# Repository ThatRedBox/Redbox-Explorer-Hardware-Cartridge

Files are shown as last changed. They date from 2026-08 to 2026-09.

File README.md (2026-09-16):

Redbox banner

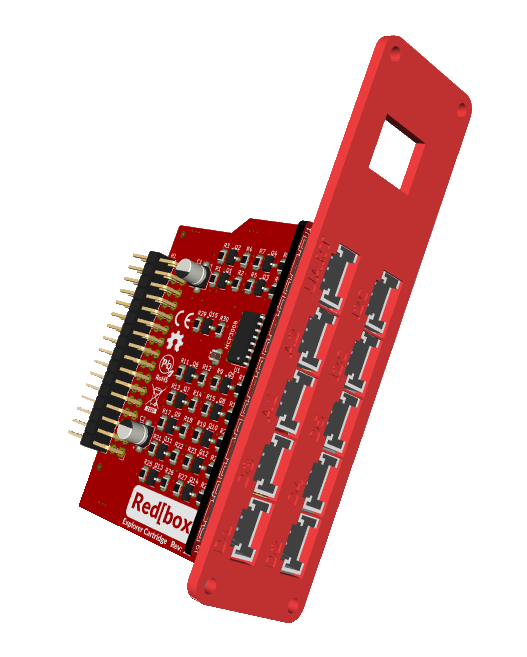
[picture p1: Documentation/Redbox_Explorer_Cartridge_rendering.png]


The **Redbox Explorer Hardware Cartridge** is designed for easily connecting sensors, actuators, and other peripherals to your system. It features the widely used `HY2.0-4P` connector (commonly referred to as the _Grove_ connector), compatible with modules and breakouts from popular ecosystems like [Grove](https://www.seeedstudio.com/catalogsearch/result/?q=grove), [Crowtail](https://www.elecrow.com/catalog/category/view/s/crowtail/id/13/), and [STEMMA](https://www.adafruit.com/category/1005).

#### Ports:
- **5x Digital in/out** (with PWM on D1)
- **2x Analog input** (0-5V)
- **1x UART**
- **2x I2C**

<br/>

 <br/>


<br clear="right"/>

## Usage

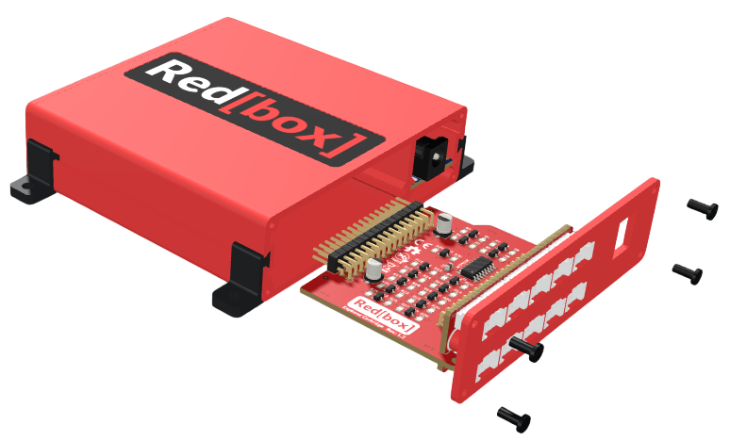
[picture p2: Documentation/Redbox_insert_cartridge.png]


The _Explorer Hardware Cartridge_ slides into the expansion slot in the back of the controller. The faceplate model for 3D printing can be found [here](Documentation/Redbox_Explorer_Cartridge_faceplate.stl). 

Connect modules from a wide range of ecosystems using the `HY2.0-4P` connector to their respective port type (analog/digital/...).

<br clear="right"/>

### Layout

| Port | Type | Raspberry Pi GPIO Pin | Info |
|---|---|---|---|
| **D1** | Digital I/O  | GPIO12 <br/>GPIO20 | Hardware PWM capable* |
| **D2** | Digital I/O  | GPIO21 <br/>GPIO16 | |
| **D3** | Digital I/O  | GPIO13 <br/>GPIO24 | |
| **D4** | Digital I/O  | GPIO25 <br/>GPIO22 | |
| **D5** | Digital I/O  | GPIO23 <br/>GPIO27 | |
| **A1** | Analog input <br/> 0...5V | *ADC* CH0 <br/>*ADC* CH1  | via MCP3008 on SPI |
| **A2** | Analog input <br/> 0...5V | *ADC* CH2 <br/>*ADC* CH3  | via MCP3008 on SPI |
| **I2C**  | I2C bus | I2C SDA <br/>I2C SDL | |
| **UART** | Serial bus | UART RX <br/>UART TX | |

_*Hardware PWM on Raspberry Pi 3B+/4B/5B/Zero 2W_

>[!WARNING]
>The digital I/O lines on this Hardware Cartridge use a passive N-MOSFET level-shifting circuit designed for compatibility with standard open-drain and push-pull I/O configurations.

## License & Collaboration
**Copyright© 2024-2026 Sanne 'SpuQ' Santens**. This project is released under the **CERN OHL-W** license. Rules & guidelines apply to the usage of the Redbox brand.

### Collaboration

If you'd like to contribute to this project, please follow these guidelines:
1. Fork the repository and create your branch from `main`.
2. Make your changes and ensure they adhere to the project's design style and conventions.
3. Test your changes thoroughly.
4. Ensure your commits are descriptive and well-documented.
5. Open a pull request, describing the changes you've made and the problem or feature they address.

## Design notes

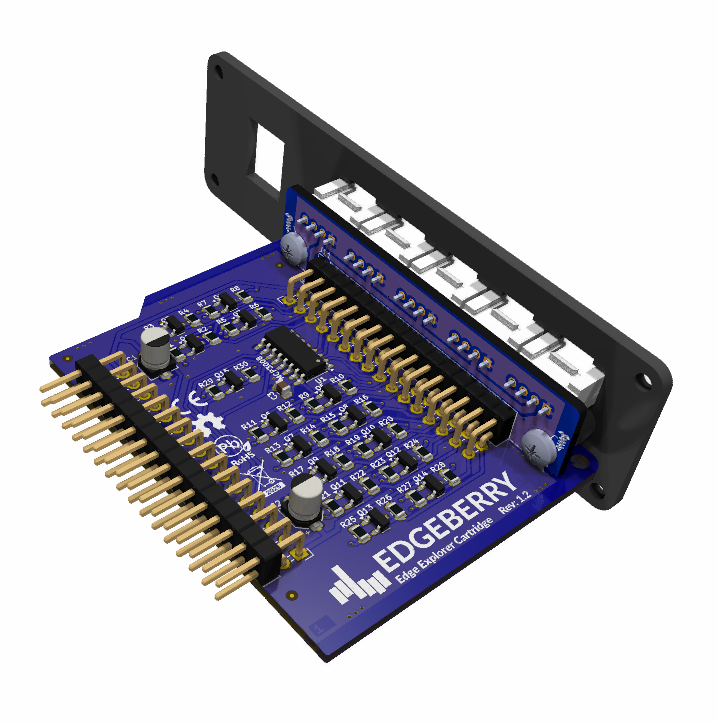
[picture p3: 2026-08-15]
Documentation/Redbox_Explorer_Cartridge_screws_2.png

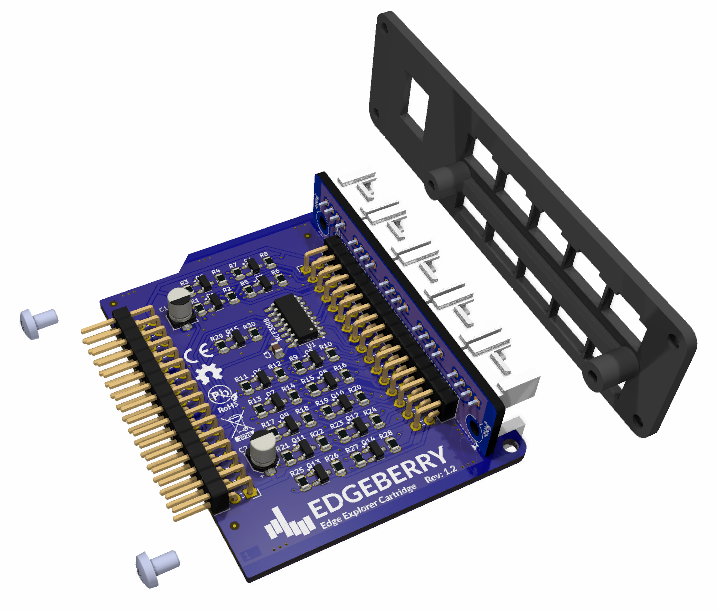
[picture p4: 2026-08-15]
Documentation/Redbox_Explorer_Cartridge_screws_1.png

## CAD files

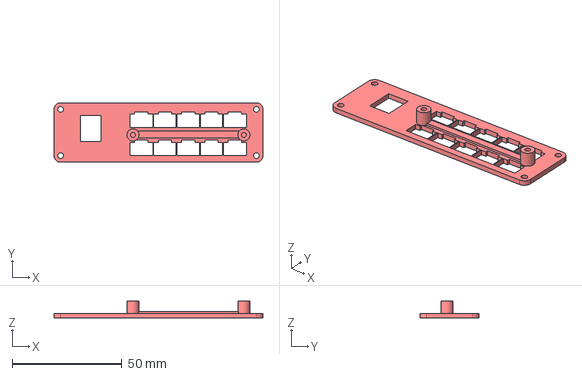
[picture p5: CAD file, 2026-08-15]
Documentation/Redbox_Explorer_Cartridge_faceplate.step
95.0 x 27.0 x 7.70 mm

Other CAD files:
Enclosure/Redbox_Explorer_Cartridge_faceplate.FCStd
Documentation/Redbox_Explorer_Cartridge_faceplate.stl

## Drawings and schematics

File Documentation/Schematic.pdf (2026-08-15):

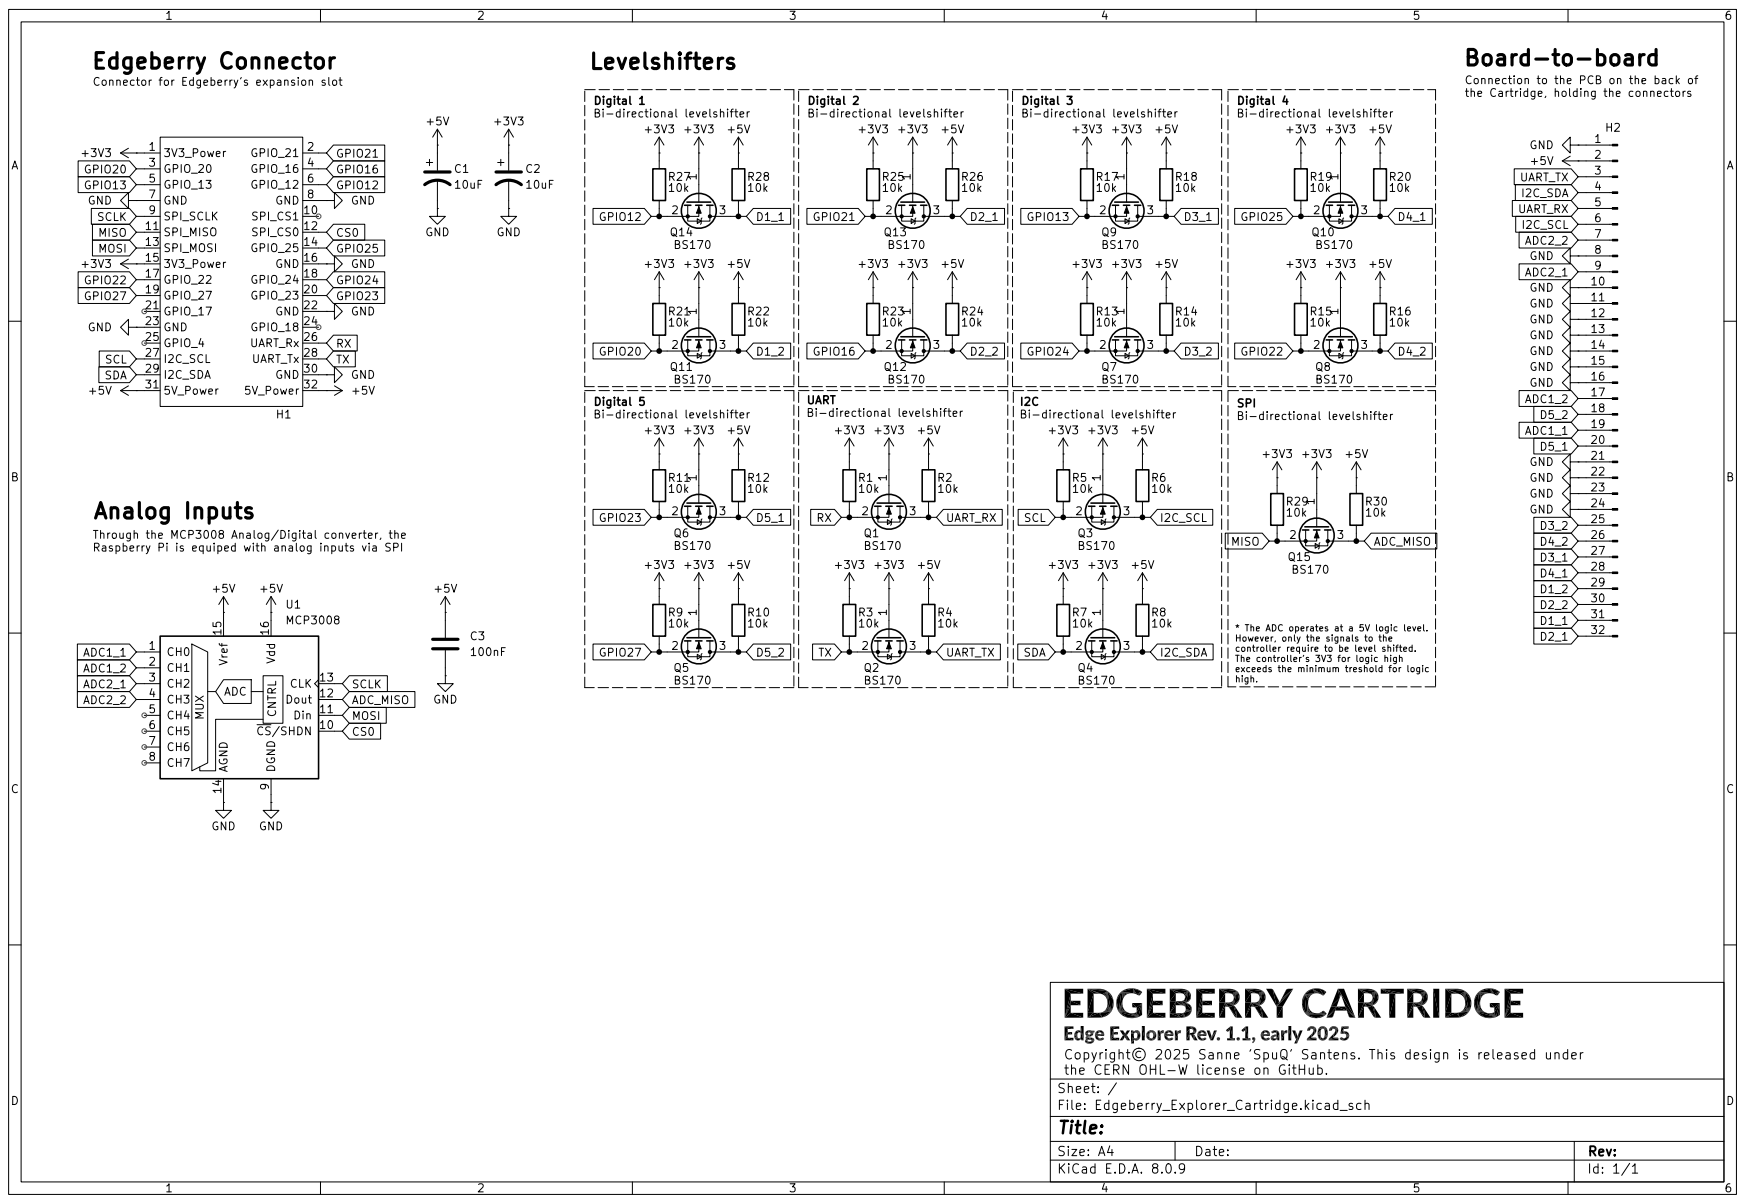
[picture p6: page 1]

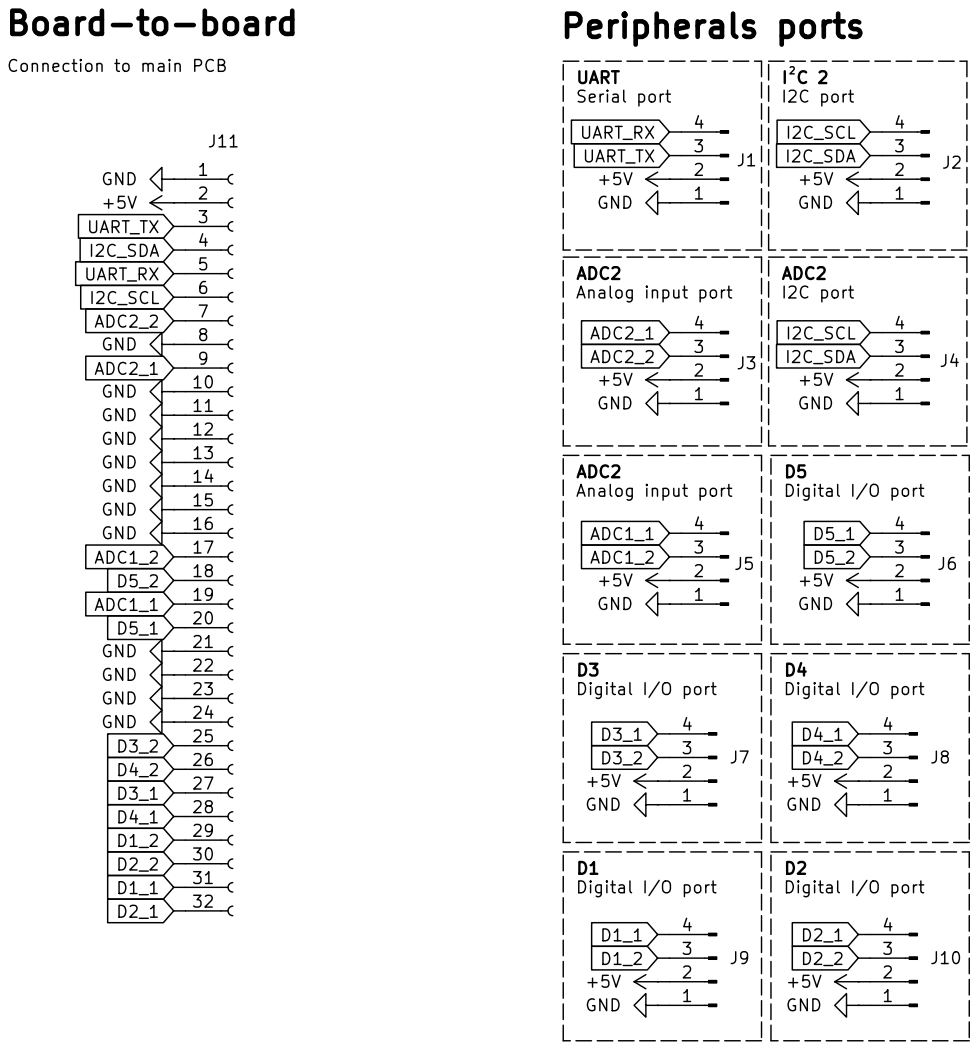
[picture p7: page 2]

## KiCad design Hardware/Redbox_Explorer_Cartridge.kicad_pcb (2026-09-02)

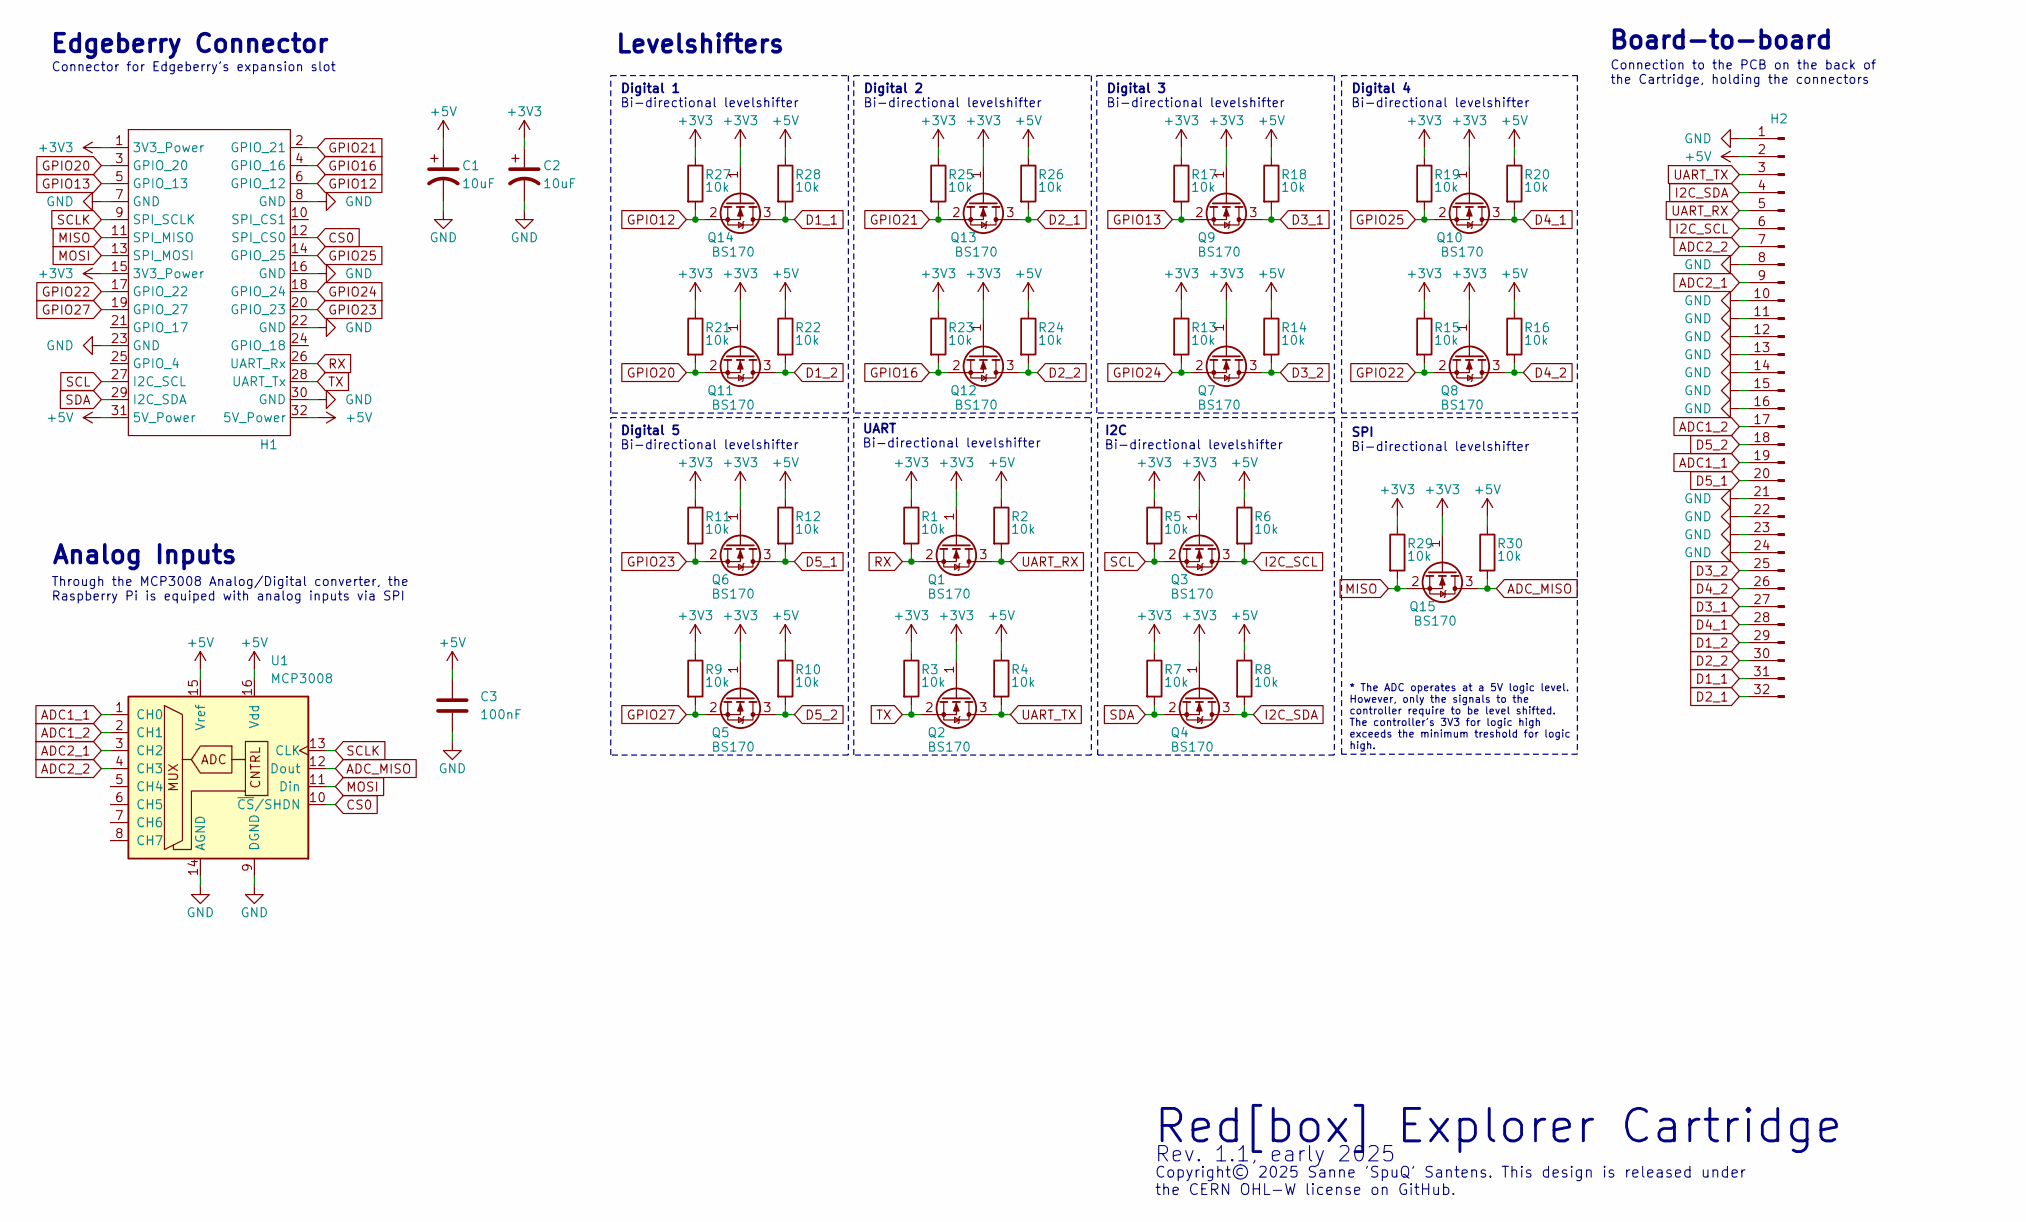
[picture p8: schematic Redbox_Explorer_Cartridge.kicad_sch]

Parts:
C1, C2: 10uF; CP_Elec_4x5.4
C3: 100nF; C_0805_2012Metric
H1: PinHeader_2x16_P2.54mm_Horizontal
H2: Conn_01x32_Pin; PinHeader_2x16_P2.54mm_Horizontal
Q1, Q2, Q3, Q4, Q5, Q6, Q7, Q8, Q9, Q10, Q11, Q12, Q13, Q14, Q15: BS170; SOT-23
R1, R2, R3, R4, R5, R6, R7, R8, R9, R10, R11, R12, R13, R14, R15, R16, R17, R18, R19, R20, R21, R22, R23, R24, R25, R26, R27, R28, R29, R30: 10k; R_0805_2012Metric
U1: MCP3008; SOIC-16_3.9x9.9mm_P1.27mm

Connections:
+3V3: C2.1, H1.1 (3V3_Power), H1.15 (3V3_Power), Q1.1 (G), Q2.1 (G), Q3.1 (G), Q4.1 (G), Q5.1 (G), Q6.1 (G), Q7.1 (G), Q8.1 (G), Q9.1 (G), Q10.1 (G), Q11.1 (G), Q12.1 (G), Q13.1 (G), Q14.1 (G), Q15.1 (G), R1.1, R3.1, R5.1, R7.1, R9.1, R11.1, R13.1, R15.1, R17.1, R19.1, R21.1, R23.1, R25.1, R27.1, R29.1
+5V: C1.1, C3.1, H1.31 (5V_Power), H1.32 (5V_Power), H2.2, R2.1, R4.1, R6.1, R8.1, R10.1, R12.1, R14.1, R16.1, R18.1, R20.1, R22.1, R24.1, R26.1, R28.1, R30.1, U1.15 (Vref), U1.16 (Vdd)
ADC1_1: H2.19, U1.1 (CH0)
ADC1_2: H2.17, U1.2 (CH1)
ADC2_1: H2.9, U1.3 (CH2)
ADC2_2: H2.7, U1.4 (CH3)
ADC_MISO: Q15.3 (D), R30.2, U1.12 (Dout)
CS0: H1.12 (SPI_CS0), U1.10 (~CS/SHDN)
D1_1: H2.31, Q14.3 (D), R28.2
D1_2: H2.29, Q11.3 (D), R22.2
D2_1: H2.32, Q13.3 (D), R26.2
D2_2: H2.30, Q12.3 (D), R24.2
D3_1: H2.27, Q9.3 (D), R18.2
D3_2: H2.25, Q7.3 (D), R14.2
D4_1: H2.28, Q10.3 (D), R20.2
D4_2: H2.26, Q8.3 (D), R16.2
D5_1: H2.20, Q6.3 (D), R12.2
D5_2: H2.18, Q5.3 (D), R10.2
GND: C1.2, C2.2, C3.2, H1.7 (GND), H1.8 (GND), H1.16 (GND), H1.22 (GND), H1.23 (GND), H1.30 (GND), H2.1, H2.8, H2.10, H2.11, H2.12, H2.13, H2.14, H2.15, H2.16, H2.21, H2.22, H2.23, H2.24, U1.9 (DGND), U1.14 (AGND)
GPIO12: H1.6 (GPIO_12), Q14.2 (S), R27.2
GPIO13: H1.5 (GPIO_13), Q9.2 (S), R17.2
GPIO16: H1.4 (GPIO_16), Q12.2 (S), R23.2
GPIO20: H1.3 (GPIO_20), Q11.2 (S), R21.2
GPIO21: H1.2 (GPIO_21), Q13.2 (S), R25.2
GPIO22: H1.17 (GPIO_22), Q8.2 (S), R15.2
GPIO23: H1.20 (GPIO_23), Q6.2 (S), R11.2
GPIO24: H1.18 (GPIO_24), Q7.2 (S), R13.2
GPIO25: H1.14 (GPIO_25), Q10.2 (S), R19.2
GPIO27: H1.19 (GPIO_27), Q5.2 (S), R9.2
I2C_SCL: H2.6, Q3.3 (D), R6.2
I2C_SDA: H2.4, Q4.3 (D), R8.2
MISO: H1.11 (SPI_MISO), Q15.2 (S), R29.2
MOSI: H1.13 (SPI_MOSI), U1.11 (Din)
RX: H1.26 (UART_Rx), Q1.2 (S), R1.2
SCL: H1.27 (I2C_SCL), Q3.2 (S), R5.2
SCLK: H1.9 (SPI_SCLK), U1.13 (CLK)
SDA: H1.29 (I2C_SDA), Q4.2 (S), R7.2
TX: H1.28 (UART_Tx), Q2.2 (S), R3.2
UART_RX: H2.5, Q1.3 (D), R2.2
UART_TX: H2.3, Q2.3 (D), R4.2

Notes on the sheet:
Bi-directional levelshifter
Edgeberry Connector
SPI
Digital 4
Board-to-board
Digital 3
Digital 2
Connection to the PCB on the back of the Cartridge, holding the connectors
I2C
* The ADC operates at a 5V logic level. However, only the signals to the controller require to be level shifted. The controller's 3V3 for logic high exceeds the minimum treshold for logic high.
Analog Inputs
Connector for Edgeberry's expansion slot
Through the MCP3008 Analog/Digital converter, the Raspberry Pi is equiped with analog inputs via SPI
Digital 5
Rev. 1.1, early 2025
Levelshifters
Copyright© 2025 Sanne 'SpuQ' Santens. This design is released under the CERN OHL-W license on GitHub.
Red[box] Explorer Cartridge
Digital 1
UART

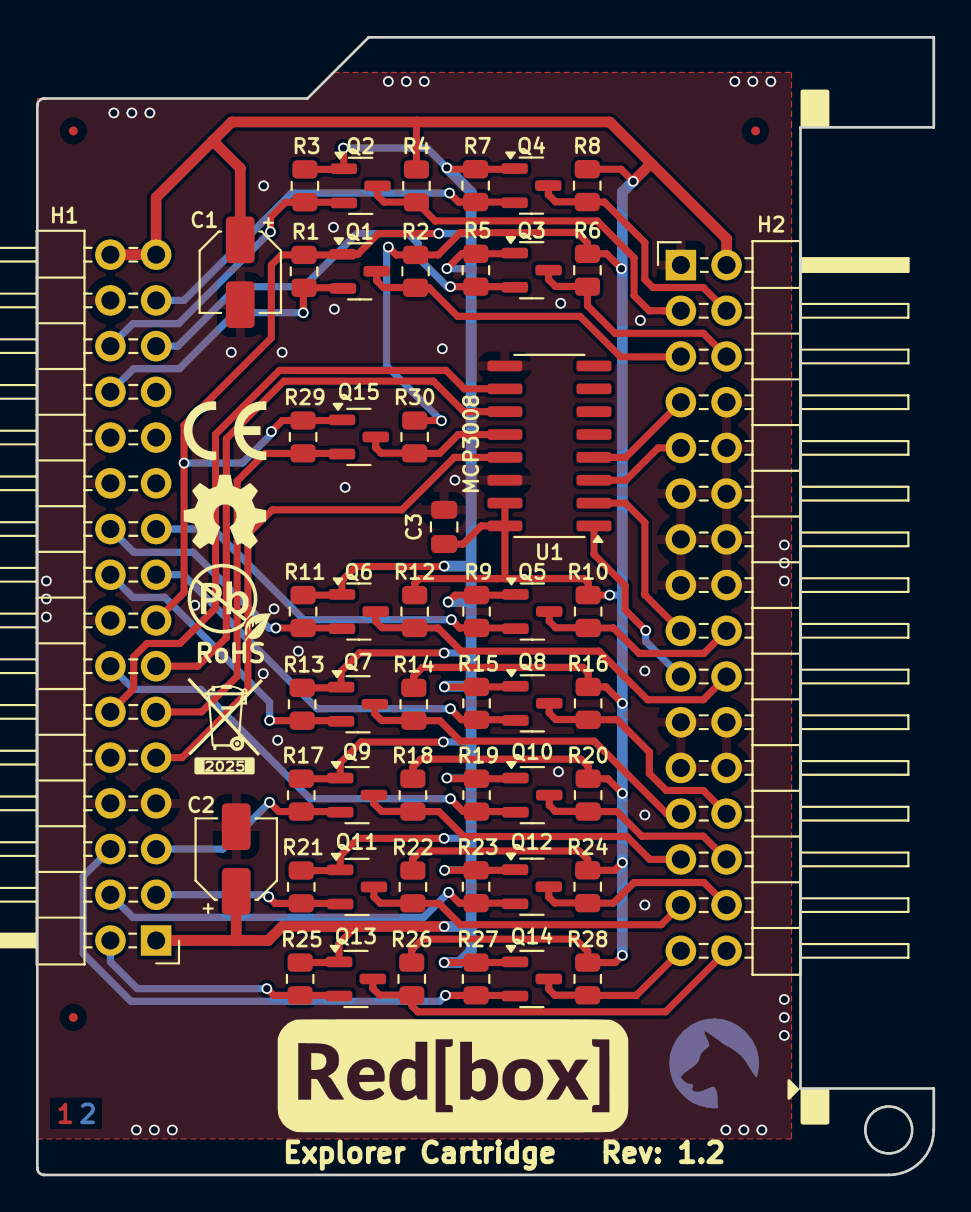
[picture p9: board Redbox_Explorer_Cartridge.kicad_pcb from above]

Board: 2 copper layers, 49.8 x 63.2 mm, 51 parts (0 on the bottom side), 40 nets.

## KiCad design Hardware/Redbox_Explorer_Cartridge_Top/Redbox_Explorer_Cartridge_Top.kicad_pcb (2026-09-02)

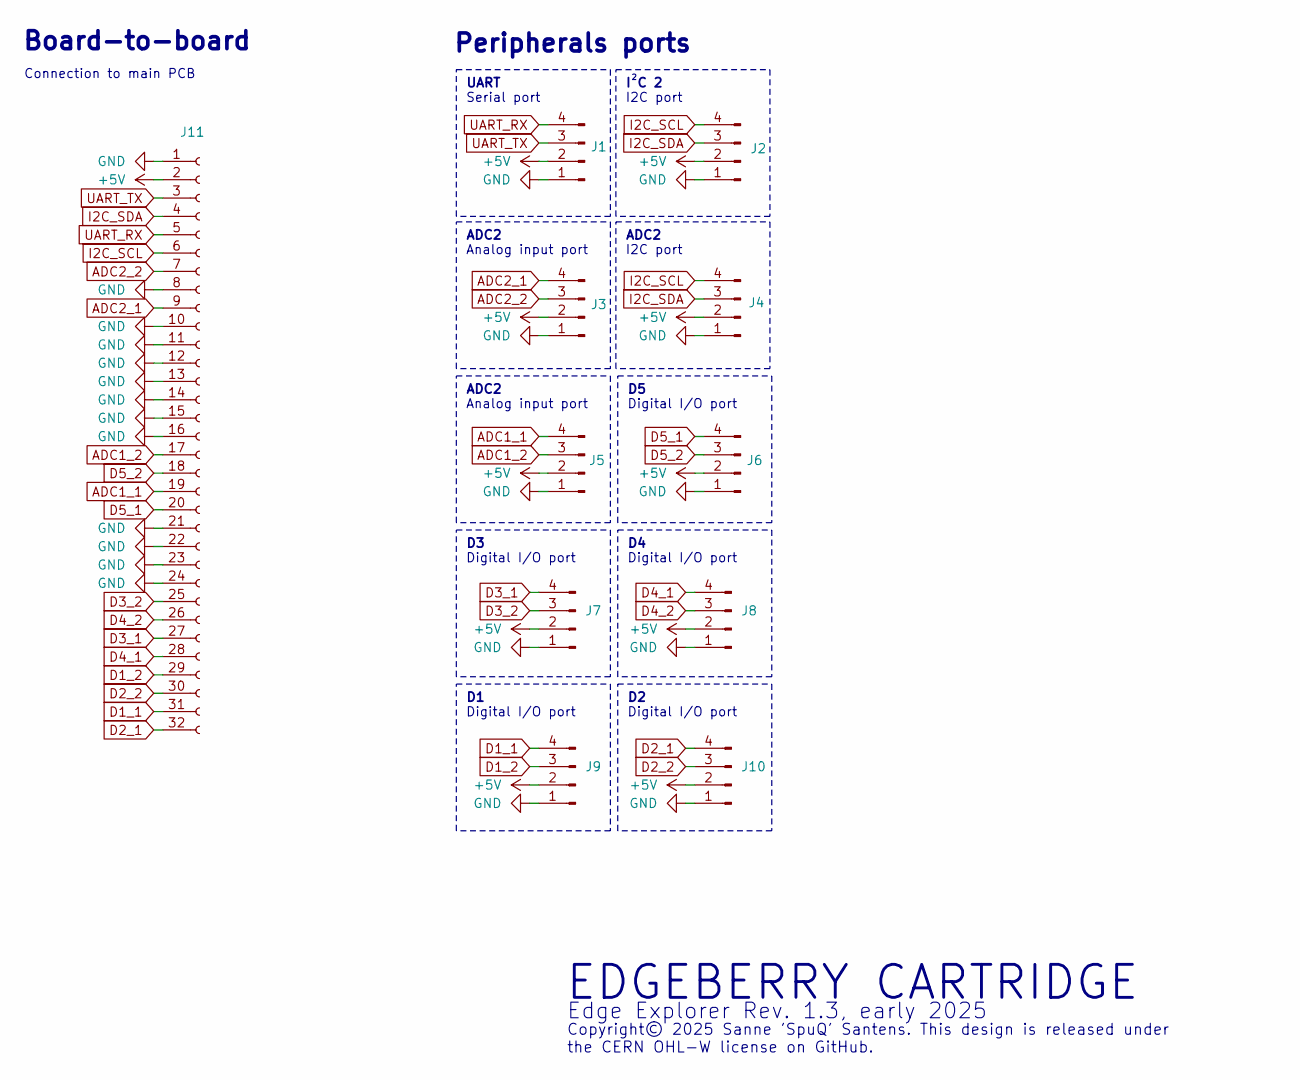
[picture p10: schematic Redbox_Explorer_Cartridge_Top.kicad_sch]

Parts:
J1, J2, J3, J4, J5, J6, J7, J8, J9, J10: Conn_01x04_Pin; HY-2.0-Grove-vertical
J11: Conn_01x32_Socket; PinSocket_2x16_P2.54mm_Vertical

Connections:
+5V: J1.2, J2.2, J3.2, J4.2, J5.2, J6.2, J7.2, J8.2, J9.2, J10.2, J11.2
ADC1_1: J5.4, J11.19
ADC1_2: J5.3, J11.17
ADC2_1: J3.4, J11.9
ADC2_2: J3.3, J11.7
D1_1: J9.4, J11.31
D1_2: J9.3, J11.29
D2_1: J10.4, J11.32
D2_2: J10.3, J11.30
D3_1: J7.4, J11.27
D3_2: J7.3, J11.25
D4_1: J8.4, J11.28
D4_2: J8.3, J11.26
D5_1: J6.4, J11.20
D5_2: J6.3, J11.18
GND: J1.1, J2.1, J3.1, J4.1, J5.1, J6.1, J7.1, J8.1, J9.1, J10.1, J11.1, J11.8, J11.10, J11.11, J11.12, J11.13, J11.14, J11.15, J11.16, J11.21, J11.22, J11.23, J11.24
I2C_SCL: J2.4, J4.4, J11.6
I2C_SDA: J2.3, J4.3, J11.4
UART_RX: J1.4, J11.5
UART_TX: J1.3, J11.3

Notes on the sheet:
I C 2
Copyright© 2025 Sanne 'SpuQ' Santens. This design is released under the CERN OHL-W license on GitHub.
Digital I/O port
Edge Explorer Rev. 1.3, early 2025
Peripherals ports
Analog input port
Serial port
I2C port
ADC2
Connection to main PCB
EDGEBERRY CARTRIDGE
UART
Board-to-board

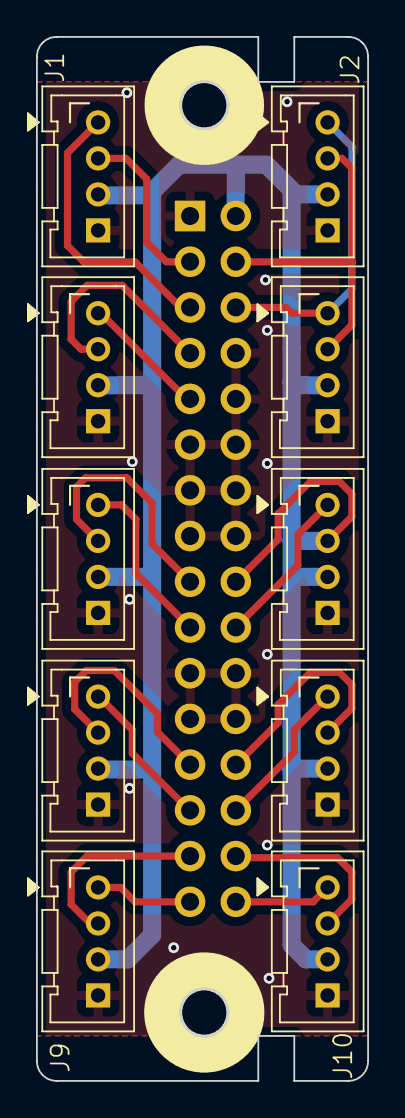
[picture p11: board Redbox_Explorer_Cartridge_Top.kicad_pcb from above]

Board: 2 copper layers, 18.4 x 58.0 mm, 11 parts (1 on the bottom side), 20 nets.

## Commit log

2026-08-15 Faceplate improvements + documentation
    [Edgeberry_Explorer_Cartridge.kicad_pcb, Edgeberry_Hardware_Cartridge_faceplate.step]
2026-08-15 Project structure: hardware
    [Redbox_Explorer_Cartridge.kicad_pcb, Redbox_Explorer_Cartridge.kicad_sch, Redbox_Explorer_Cartridge_Top.kicad_pcb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]
2026-08-15 Project reorganization + paths corrections
    [Edgeberry_Hardware_Cartridge_faceplate.FCStd, Redbox_Explorer_Cartridge.kicad_pcb, Redbox_Explorer_Cartridge_faceplate.FCStd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]
2026-09-01 ReadMe: insert Cartridge
2026-09-02 Brand colors update
    [Redbox_Explorer_Cartridge.kicad_pcb, Redbox_Explorer_Cartridge_Top.kicad_pcb]
2026-09-15 Documentation: faceplate STL
    [Redbox_Explorer_Cartridge_faceplate.stl]
